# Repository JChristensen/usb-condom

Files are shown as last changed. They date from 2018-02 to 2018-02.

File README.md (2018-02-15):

# USB Condom
https://github.com/JChristensen/usb-condom  
README file  
Jack Christensen Feb-2018

## Overview
A little something for the tinfoil hat crowd. Amaze your friends, confound your enemies, spread FUD far and wide or just have a good laugh.

This is just my implementation of a concept that's been around for a while. The idea is that USB charging ports in public places (airport kiosks, hotels, coffee shops, etc.) should be considered untrusted because it's possible they could contain technology that attempts to access data on mobile devices plugged in for charging. The USB Condom prevents this because it passes the power through but not the USB data lines. Just pop it on the end of any USB cable and you're practicing safe charging! From what I can tell, there are almost no documented instances of such a thing actually occurring. There might have been a [demonstration at DEF CON.](https://krebsonsecurity.com/2011/08/beware-of-juice-jacking/) So mostly this is just a fun project, but hey, it can't hurt, right?

PC boards can be ordered [from OSH Park](https://www.oshpark.com/shared_projects/0s1QDkyq).
A bill of materials is available [at Mouser Electronics](https://www.mouser.com/ProjectManager/ProjectDetail.aspx?AccessID=3e867db098) and also in this repo.

## CC BY-SA
"USB Condom" by Jack Christensen is licensed under [CC BY-SA 4.0](https://creativecommons.org/licenses/by-sa/4.0/).

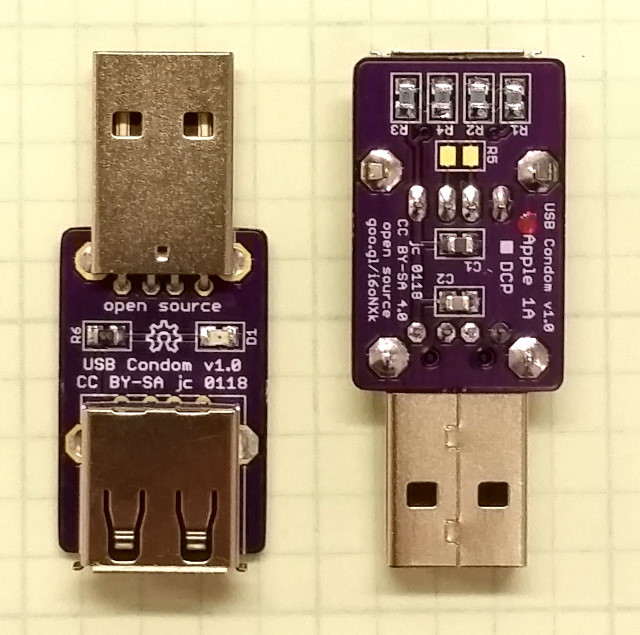
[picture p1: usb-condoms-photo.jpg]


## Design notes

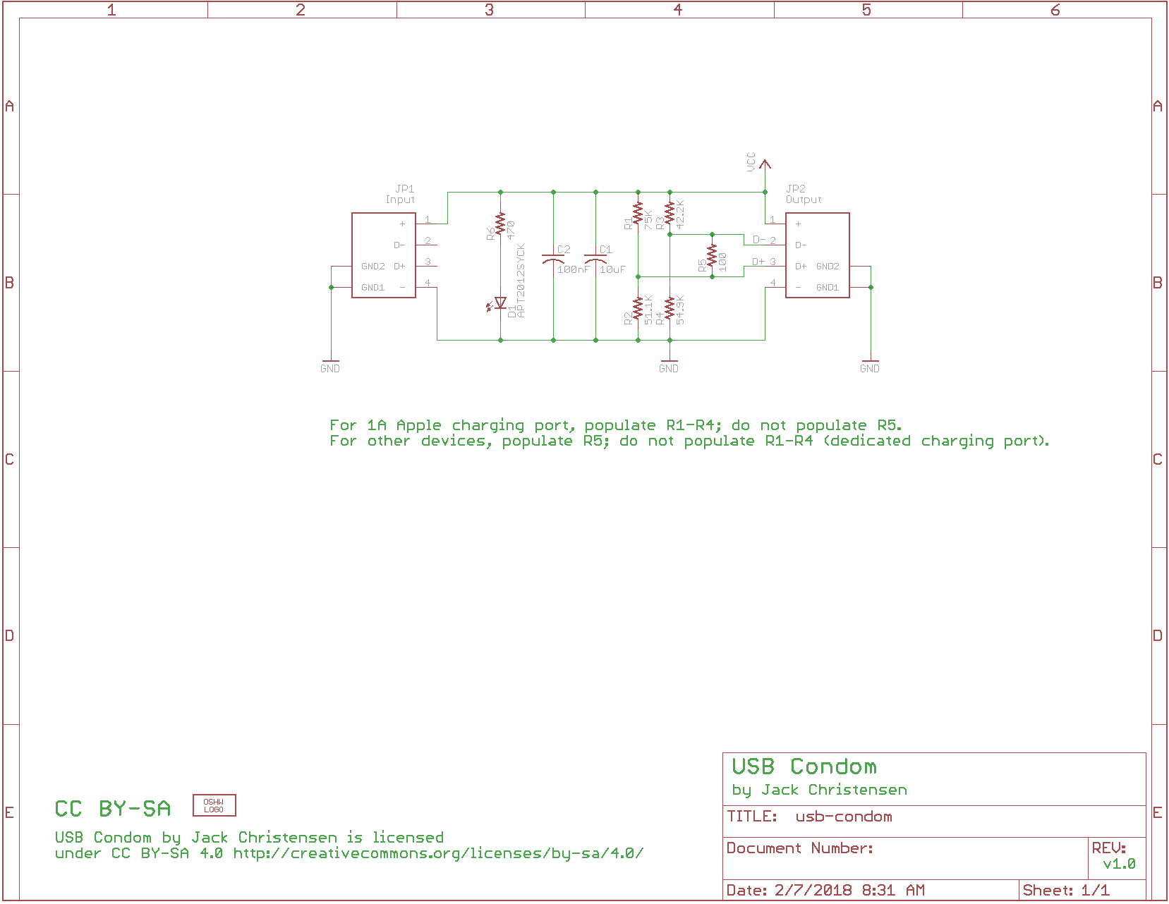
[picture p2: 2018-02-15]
schematic.png

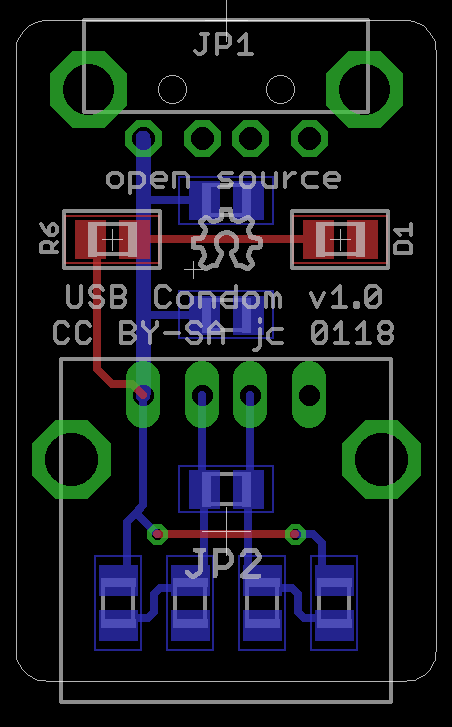
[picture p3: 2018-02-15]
board.png

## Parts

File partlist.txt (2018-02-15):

Partlist

Exported from usb-condom.sch at 2/15/2018 12:25 PM

EAGLE Version 7.5.0 Copyright (c) 1988-2015 CadSoft

Assembly variant: 

Part     Value          Device     Package             Library  Sheet

C1       10uF           C-USM0805  M0805               _jc      1
C2       100nF          C-USM0805  M0805               _jc      1
D1       APT2012SYCK    LEDM0805   M0805               _jc      1
JP1      Input          UP2-AH-TH  UP2-AH-X-TH         _jc      1
JP2      Output         USB-A      USB-A-S-RA-ADAMTECH _jc      1
R1       75K            R-US_M0805 M0805               _jc      1
R2       51.1K          R-US_M0805 M0805               _jc      1
R3       42.2K          R-US_M0805 M0805               _jc      1
R4       54.9K          R-US_M0805 M0805               _jc      1
R5       100            R-US_M0805 M0805               _jc      1
R6       470            R-US_M0805 M0805               _jc      1

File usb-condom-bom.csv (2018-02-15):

USB Condom
Bill of Materials
https://github.com/JChristensen/usb-condom
https://www.mouser.com/ProjectManager/ProjectDetail.aspx?AccessID=3e867db098
Mouser Part No. | Mfr. Part No. | Manufacturer | Description | Order Qty.
523-UE27AC5410H | UE27AC5410H | Amphenol | USB Connectors RA USB A | 1
490-UP2-AH-1-TH | UP2-AH-1-TH | CUI Inc. | USB Connectors USB 2.0 type A plug 4 pin Horizontal TH | 1
604-APT2012SYCK | APT2012SYCK | Kingbright | Standard LEDs - SMD YELLOW WATER CLEAR | 1
80-C0805C104K3R | C0805C104K3RACTU | KEMET | Multilayer Ceramic Capacitors MLCC - SMD/SMT 25volts 0.1uF X7R 10% | 1
603-CC805KKX5R7BB106 | CC0805KKX5R7BB106 | Yageo | Multilayer Ceramic Capacitors MLCC - SMD/SMT 10uF 16V X5R 10% | 1
603-RC0805FR-07100RL | RC0805FR-07100RL | Yageo | Thick Film Resistors - SMD 100 OHM 1% | 1
603-RC0805FR-07330RL | RC0805FR-07330RL | Yageo | Thick Film Resistors - SMD 330 OHM 1% | 1
603-RC0805FR-0754K9L | RC0805FR-0754K9L | Yageo | Thick Film Resistors - SMD 54.9K OHM 1% | 1
603-RC0805FR-0742K2L | RC0805FR-0742K2L | Yageo | Thick Film Resistors - SMD 42.2K OHM 1% | 1
660-RK73H2ATTD5112F | RK73H2ATTD5112F | KOA Speer | Thick Film Resistors - SMD 1/4W 51.1K OHM 1% | 1
603-RC0805FR-0775KL | RC0805FR-0775KL | Yageo | Thick Film Resistors - SMD 75K OHM 1% | 1

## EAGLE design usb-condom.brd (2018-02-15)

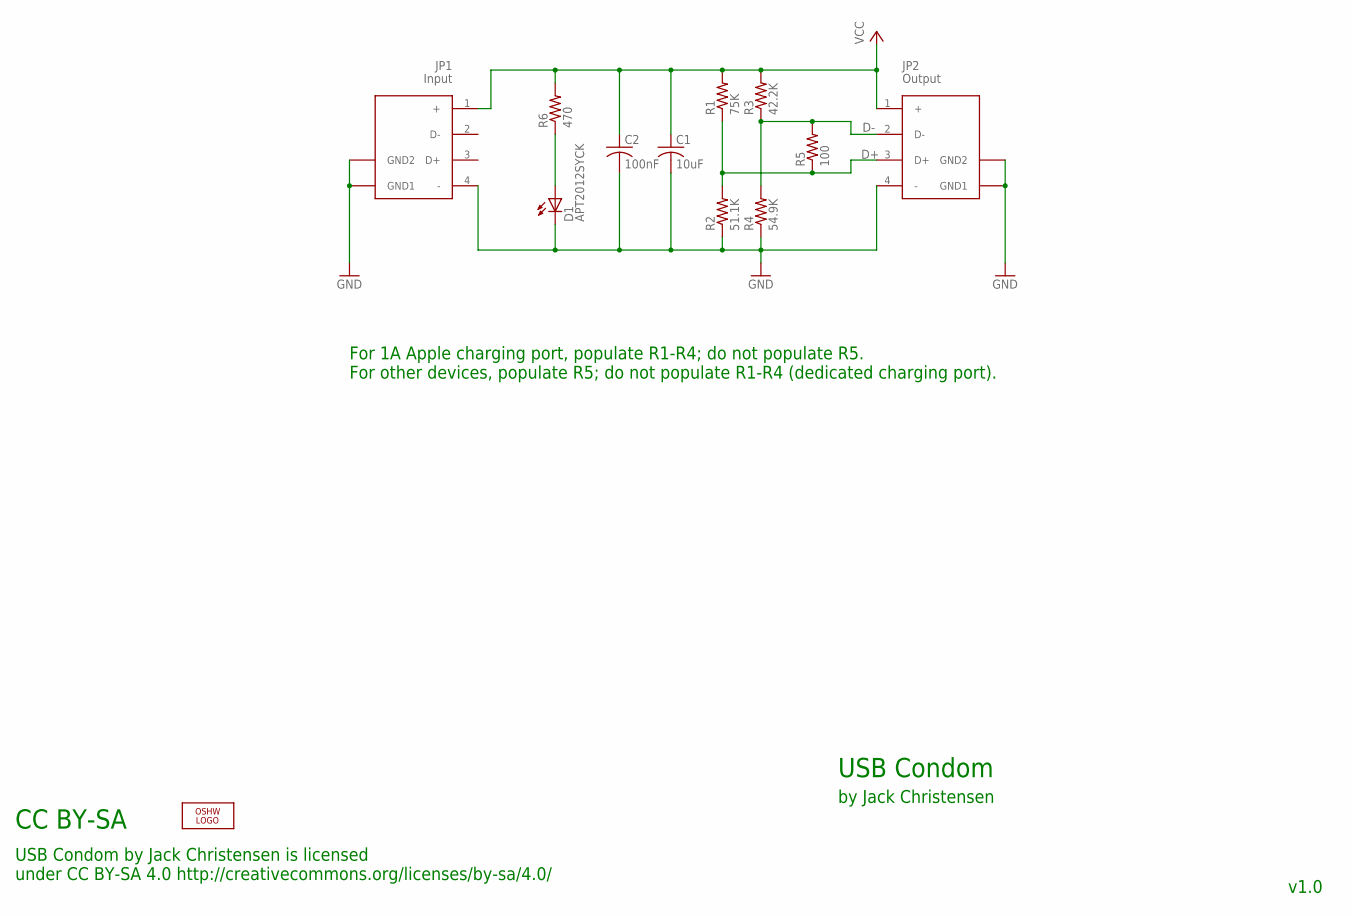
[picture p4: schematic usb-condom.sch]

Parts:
C1: 10uF; M0805
C2: 100nF; M0805
D1: APT2012SYCK; M0805
JP1: Input; UP2-AH-X-TH
JP2: Output; USB-A-S-RA-ADAMTECH
LOGO1: OSHW_LOGO_8MILX0100-NT; OSHW_8X100_NOTEXT
R1: 75K; M0805
R2: 51.1K; M0805
R3: 42.2K; M0805
R4: 54.9K; M0805
R5: 100; M0805
R6: 470; M0805

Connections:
D+: JP2.3 (D+), R1.1, R2.2, R5.1
D-: JP2.2 (D-), R3.1, R4.2, R5.2
GND: C1.2, C2.2, D1.2 (C), JP1.4 (-), JP1.P$5 (GND1), JP1.P$6 (GND2), JP2.4 (-), JP2.GND1, JP2.GND2, R2.1, R4.1
unnamed: D1.1 (A), R6.1
VCC: C1.1, C2.1, JP1.1 (+), JP2.1 (+), R1.2, R3.2, R6.2

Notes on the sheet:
USB Condom
by Jack Christensen
v1.0
CC BY-SA
USB Condom by Jack Christensen is licensed under CC BY-SA 4.0 http://creativecommons.org/licenses/by-sa/4.0/
For 1A Apple charging port, populate R1-R4; do not populate R5. For other devices, populate R5; do not populate R1-R4 (dedicated charging port).

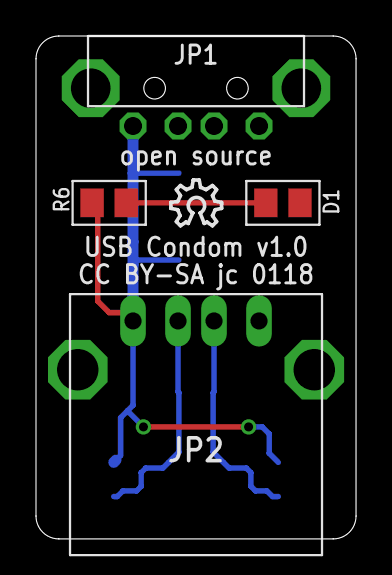
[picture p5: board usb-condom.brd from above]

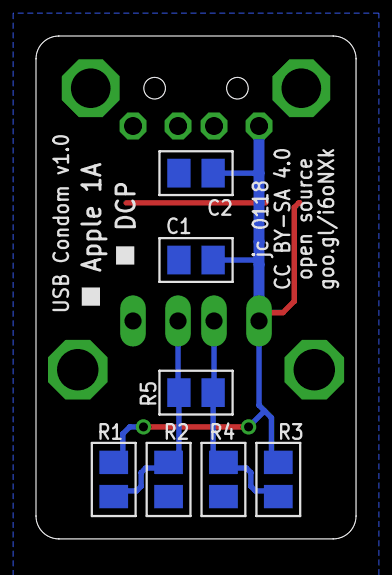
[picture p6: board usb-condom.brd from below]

Board: 2 copper layers, 17.8 x 27.9 mm, 12 parts (7 on the bottom side), 5 nets.

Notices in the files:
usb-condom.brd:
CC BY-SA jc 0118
